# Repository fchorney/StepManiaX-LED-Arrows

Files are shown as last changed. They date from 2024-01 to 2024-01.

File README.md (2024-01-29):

# StepManiaX LED Mirroring Project
The goal of this project is to create 5 3D printed arrows with LEDs in them connected
to your StepManiaX (SMX) stage to mirror the steps that you are stepping.

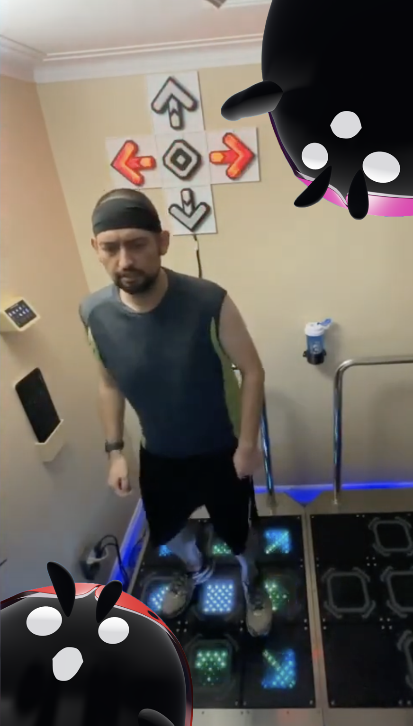
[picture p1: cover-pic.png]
Cover Image


This project requires:
- 3D Printing
- Soldering
- Wire Crimping
- Super Gluing
- Hot Gluing
- Various other small but not insignificant tasks.

Throughout this guide I will be linking all the products I used to create the finished product
but you are by no means required to use exactly the same items I did. This project can be
completed in a number of ways and this is just one.

I will apologize in advance as I have not taken a lot of pictures of this process, but I will
do my best to relay everything I can in Text.

You can see a video of the finished product (The LED Arrows Behind Me) Here:
Finished Product Example (https://www.youtube.com/watch?v=8-Bkg70dLgw)

# Steps

1. [3D print models and combine](./3D%20Prints/README.md)
2. [Oder and populate the PCB](./Circuit/README.md)
3. [Wire necessary cables](./Wiring/README.md)
4. [Putting it all together](./Finishing/README.md)

# Problems? Comments? 
If you had **ANY** problems with this guide, have improvement ideas on the project, or if you think certain sections 
could be expanded or refined, please don't hesitate to let me know.
I encourage you to open up an [Issue](https://github.com/fchorney/StepManiaX-LED-Arrows/issues),
or even a [Pull Request](https://github.com/fchorney/StepManiaX-LED-Arrows/pulls) if you know what you want changed.

I will be sure to check them out, and continue to make this guide better. 

# Future Updates
I already have a big list of upgrades that I want to make to this project for version 2. I can't promise it will happen
any time soon, but hopefully sometime this year. 

Here is a sneak peek of the ideas I want to work on for version 2:
- Snap Connectors for all 3D parts.
  - Trying to avoid as much glue as possible
- Cable channel on backplate could be deeper and wider
  - I personally had some issues fitting 10 x 18AWG stranded wires in the channels
- Backplate connectors need to be better
  - The small connectors really don't do much aside from align the plates. Need a better solution to connect them together
- Design for those JST-SH connectors to snap into the arrow base itself
  - The SH-series connectors are made to fit into holes, maybe leverage this for a better fit and less glue
- Use 20AWG instead of 18AWG in the future probably
  - 18 seems a little big, probably don't need it to be so thick
- Support all 9 panels
- RGB Addressable LEDs
  - Everything can run off of 5v this way, and we have way more options for customizations
- Pico-W Brains
  - This may cause **some** latency since it won't be a purely analog circuit anymore, but this would give crazy customization
  - Different modes, change colors for every step, pulse on freeze, rainbow, etc
- Stream Integration
  - If we use a Pico-W, since it had wifi there is a possibility you could write some code to connect it to twitch chat
and let chat spend points/bits/etc to control the arrows
- Maybe just use screw terminals for all circuit board inputs to be consistent
  - Having to use a handful of different connector types is kind of annoying
- Small PCB LEDs for inputs
  - Might be nice to show what the inputs are with small leds on the pcb
- Can we intercept the SMX data going to the panels to display the judgement color?
  - Theoretically when you hit a panel, it tells the game you hit it and the game judges you and sends back the judgement.
  - We can maybe man in the middle this to figure it out, and actually light our arrows the color the game tells us to.

# Donate
If you appreciate my work and would like to buy me a coffee, I would very much appreciate it. Donations are always welcome,
but never necessary.



# Special Thanks
Big thanks to the [Step Revolution](https://www.steprevolution.com/) crew for making a super fun game, being cool with me
making this kind of stuff, and even helping me out with some aspects of it.

Thanks to [Daaanty](https://www.twitch.tv/daaanty) for giving me some great ideas for the arrow models as well as helping
me track down some of the harder to find connectors. 

Thanks to Cube for making this helpful [SMX Pad to Andamiro Cabinet](https://docs.google.com/document/d/1XnCEbnF3oVle8vsj_GakjsSuEs43jKPMqEG-YfRb-IE/edit#heading=h.98pnc1v5ryli)
guide which helped me confirm some wiring.

Make sure to check out the [Official StepManiaX Discord](https://discord.gg/stepmaniax-430779485026254848) where you
can find a lot of us chatting about SMX and talking about fun projects like this!

# ⚠️ WARNING ⚠️
Making this project and messing with your StepManiaX stages are entirely at your own discretion. 
StepRevolution and I provide absolutely **NO** warranty if something happens to go wrong.

# License
All materials in this project are licensed as [CC BY-NC-SA 4.0](https://creativecommons.org/licenses/by-nc-sa/4.0/) unless otherwise specified.

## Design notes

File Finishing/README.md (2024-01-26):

# Finishing the project

At this point we can assume you have the following items from the previous sections:
- 4 x 3D Printed Arrow Bases + Connected (glued) Insert/Tops
- 1 x 3D Printed Center Base + Connected (glued) Inserts/Tops
- 5 x 3D Printed Back Plates
- 4 x 3D Printer Back Plate Connectors
- 1 x SMX Wire Harness/Splitter (already installed in SMX pad)
- 1 x SMX Molex -> JST XH-Series cable (already installed in SMX pad)
- 1 x Circuit Board (populated and soldered together)

Tools and products you will need for finishing:
- Hot Glue Gun w/ Hot Glue Sticks
- Super Glue
- [12v 7A DC Power Supply](https://www.aliexpress.us/item/1005006333977811.html) 
- [18/20/22 AWG Stranded Hookup Wire (Black, Red)](https://www.aliexpress.us/item/1005002288468147.html)
- [HSC8 6-4 Ferrule Crimper](https://www.amazon.ca/gp/product/B08CXT9Y8L/ref=ppx_yo_dt_b_search_asin_title)
- [Ferrule Terminal Kit](https://www.amazon.ca/Lytool-Insulated-Connectors-Terminals-Single-Line/dp/B0BY2CS16J/ref=sr_1_8)
- [Heat Shrink Tubing](https://www.amazon.ca/Wirefy-180-Heat-Shrink-Tubing/dp/B084GDLSCK/ref=sr_1_5)
- [1/2 Inch Braided Cable Sleeves](https://www.amazon.ca/Pack-33ft-Protector-Expandable-Sleeving/dp/B07ZT9PL72/ref=sr_1_12)
- [JST-SM Male/Female 2P Connectors](https://www.aliexpress.us/item/1005005780885587.html)
- Soldering Station
  - SN63/PB37 Solder
  - Solder Flux

Notes:
- For the 12v power supply, you won't need 7A for just one pad. It's up to you to figure out how many amps you'll need
based on how many LEDs you are powering. 
- For the hookup wire, I opted to use a thicker AWG for going from the circuit board to the LEDs as the distance
travelled is fairly long and I figured a thicker cable would be better in that case. From what I've read, 22 AWG
should realistically be more than enough to carry about 1A of power to each arrow.

## Power Supply
Assuming you bought a similar power supply to the one linked in the materials above, you will need to cut off the DC 
end of the cable and attach some Ferrule ends to the ground and live wires since we're using screw terminals rather
than a barrel jack. 

Simply snip off the barrel jack at the end, expose enough of the 2 wires (typically black and red), remove some of the
wire jacket and terminate with ferrules of the correct size using a ferrule crimper. These will simply go into the 
12v input screw terminals on our circuit board. 

If you are making 2 (for 2 SMX pads) you can terminate some 18AWG (or thicker) wire with ferrules on both ends to daisy
chain the 2 circuit board 12v supplies together. 

## 3D Prints
### Back Plates
At this point we can finish up our 3D prints and wiring for the LEDs. 

Firstly you'll want to super glue all the back plates together. I suggest lining them all up in the plus shape (
4 cardinal arrows and one center panel), use some super glue on the touching edges, add some super glue to the back
plate connector slot and put a back plate connector in each relevant slot (the 4 in the center panel). Leave this alone
to harden over time.

### Arrows
Once the back plates have been securely glued together, you can glue the arrow bases (not the insert/tops) to the 5
back plates. Simply add some super glue to the indent on the bottom of each center/arrow base, line it up with the back
plate so the nub in the middle of the back plate goes in to the base indent, line up the wire holes on the base with
the ones on the back plate, and leave it to harden. This might take a while to harden as the super glue won't really be
exposed to a lot of air there. 

## Wiring
So now we have the backplates and arrow bases securely glued to each other. At this point you're going to want to 
determine how much wiring you will need for each arrow to reach the circuit board for your specific setup. As you can
see in the picture in the base of the repo, my arrows are fairly high up my wall and the wire goes all the way down to
the ground. I determined how much stranded wire I would need for each arrow and cut the pieces. 

For each arrow, you will want to solder your stranded hookup wire (I suggest 18 or 20 AWG) to the opposite type of 
JST-SM connector that you used in the arrow LED section. If you used male for the LEDs, use female for these wires, or
vice versa. What I did was expose wire from the JST-SM connectors, as well as my stranded wire, connected them together,
by twisting, soldered them together and applied some heat shrink to protect the connection. Do this for all 5 pairs of
wire.

At this point you want to route your wire (the non connector side) through the cable holes of the arrow bases/back plates
so that you end up with the connector inside the arrow. Connect the 2 JST-SM connectors, and use some hot glue to provide
strain relief at the holes, and keep all wires down and in place. 

Now that we have wires coming out of the back of all 5 arrows, you essentially want to route them all through the cable
channels on the back of the backplates so they all come out of the bottom arrow. Use hot glue liberally here to keep
them in place and provide strain relief.

This step is optional, but I used 1/2 inch braided cable sleeves to contain all 10 of my wires coming out of the bottom
arrow until it hits my circuit board. Use the cable sleeves, as well as some heat shrink tubing to make it look nice.

Now you can clip the ends of the wire group to be flush if you'd like, and use the ferrule crimper to crimp ferrules
onto the 10 LED wires. 

### Glue Arrow Tops

You can now superglue the arrow inserts/tops onto the arrow bases.

❗Warning: Remember, this is essentially permanent at this point, so make sure all your wiring is correct and working.

## Connecting
Attach these to the circuit board screw terminals that match the arrows. 

⚠️ Remember: If the arrows are behind you, the "right" input should hook up to the "left" arrow if you are looking
straight at them. Thankfully this is easy to reverse if you put it in the wrong way by switching the wires to the other
screw terminal.

Attach the JST-XH 6 pin connector coming out of your SMX stage onto the circuit board. 

Connect the power inputs (and outputs if you have them) to the circuit board.

## Mount Arrows
Stick your arrows and backplates to your wall somehow! That's up to you to figure out.

What I did was use about 8 x [3M Command Strips](https://www.command.com/3M/en_CA/p/d/v000584005/) at various points
on the back of the backplates to stick to my wall. Fairly clean and easy to remove if necessary. 

# Enjoy

Congratulations! At this point you should be finished! Turn on StepManiaX, plug in your 12v power supply and dance your
heart out! 

⚠️ If you had any issues with this guide, questions, or comments I encourage you to please open up an issue in this
repository.

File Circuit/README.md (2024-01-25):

# Circuit and PCB
I have included the necessary files to have the PCB manufactured or perf-boarded for your use. 

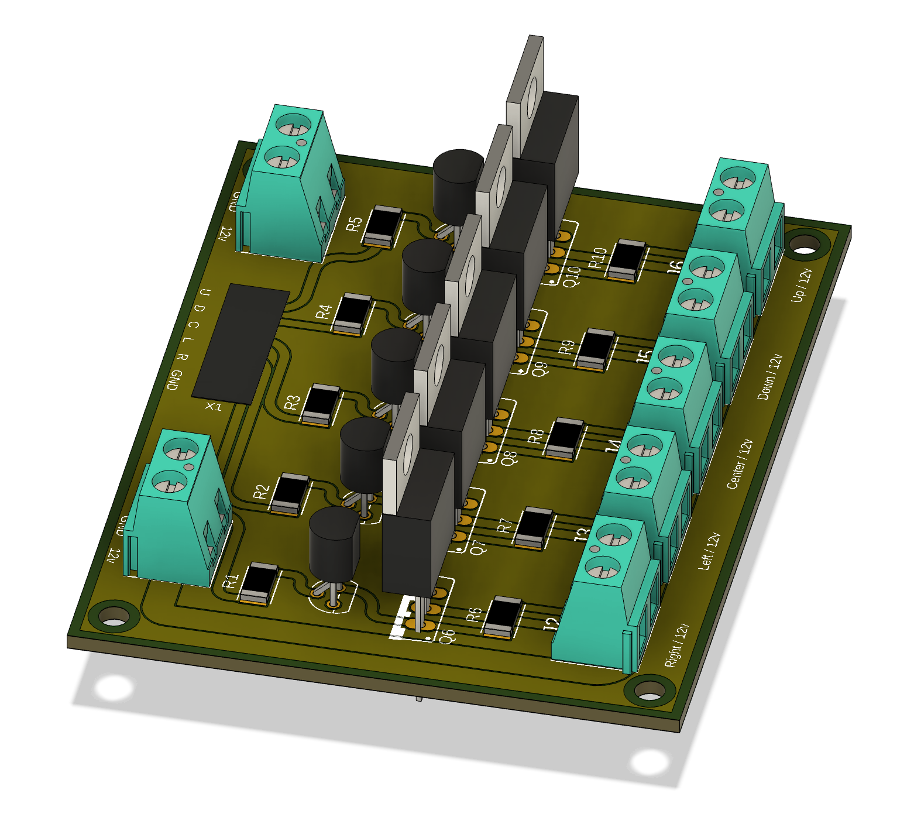
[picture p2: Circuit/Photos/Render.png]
3D Render


## Schematic
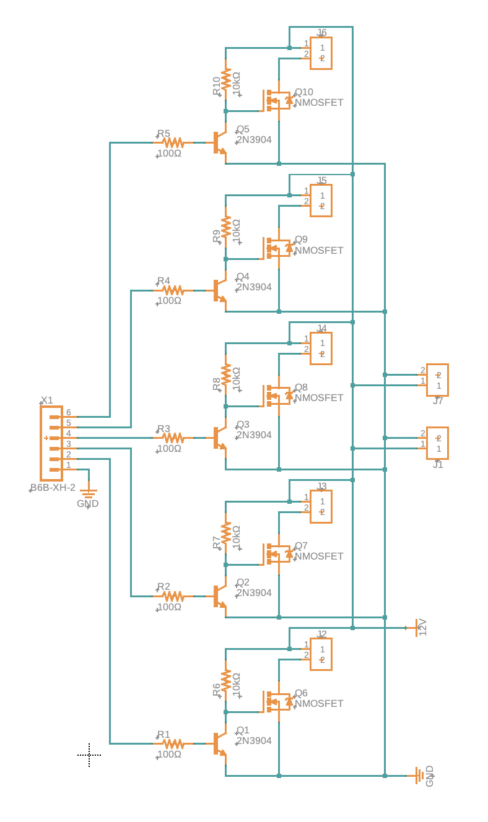
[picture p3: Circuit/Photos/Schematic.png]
Schematic


The schematic is fairly simple. We take 5 arrow data lines, plus ground, into the 6 pin JST connector, and
a 12v power supply into one of the power screw terminals. The 12v are to power the LEDs as I was using 12v single 
colour LEDs for my implementation. 

The data lines coming out of the StepManiaX panel boards sit high (5v) and when the press threshold is reached
they are pulled down to ground (0v). Since my board needs to pull the LED ground pins to ground when the SMX
panel is also pulled to ground, I had to create a logic inverter since I'm using MOSFETs to drive the 12v LEDs from
the 5v SMX logic.  

The 5v logic is passed through a 100Ω resistor into the base of a BJT
([2n3904](https://www.onsemi.com/pdf/datasheet/2n3903-d.pdf)). The collector for the BJT goes into the MOSFET
([BUZ11](https://www.onsemi.com/pdf/datasheet/buz11-d.pdf)) gate and will pull it to ground when the BJT receives a
high 5v signal since the BJT Emitter is connected to ground. When the BJT is inactive (the SMX panel signal is pulled to
ground when the panel is pressed), the MOSFET gate is connected to a 10kΩ pullup to the 12v line thus activating the
MOSFET to connect the Drain (connected to the LED Arrow) to ground, completing the circuit. 

The second 12v screw terminal on the input side, is to daisy chain 12v to a second board for a second SMX pad if you 
are planning to make two. You should note that you will want to make sure your 12v power supply can handle both boards.
I guestimated the density of LEDs on my arrows would use about 1A for each arrow, and I think in general you'd be
hitting 6 arrows max and probably hardpressed to even do that, so 7A should be more than enough for 2 pads. 

## Bill of Materials (BoM)

Realistically, most of the items I used in my circuit can be interchanged with any other part that fits the criteria. 
This BoM will list exactly what I used and where you can find it, but if you have similar parts already, you can use
those instead. Specifically the MOSFETS, as I only used BUZ11 since I had a bunch lying around.

- R1, R2, R3, R4, R5: [100Ω 2010 SMD Resistor](https://www.digikey.ca/en/products/detail/yageo/RC2010FK-07100RL/5920949)
- R6, R7, R8, R9, R10: [10kΩ 2010 SMD Resistor](https://www.digikey.ca/en/products/detail/stackpole-electronics-inc/RMCF2010FT10K0/1758376)
- Q1, Q2, Q3, Q4, Q5: [NPN BJT Transistor 2N3904 TO92](https://www.digikey.ca/en/products/detail/onsemi/2N3904BU/1413)
- Q6, Q7, Q8, Q9, Q10: [BUZ11 N-CH MOSFET](https://www.digikey.ca/en/products/detail/onsemi/BUZ11-NR4941/1954150)
- J1, J2, J3, J4, J5, J6, J7: [2P Terminal Block Side ENT 5.08mm PCB](https://www.digikey.ca/en/products/detail/phoenix-contact/5442206/4390264) 
- X1: [B6B-XH-A](https://www.digikey.ca/en/products/detail/jst-sales-america-inc/B6B-XH-A/1000381)

### Notes
- I personally accidentally bought 1206 sized resistors for my board, but the correct size is 2010.
  - If you are doing this on a perf-board or something you can use through-hole resistors if you want.
- The BUZ11 MOSFETs look unavailable at the digikey link I added up there, so you'll have to find some alternative. 
  - I'm certainly no expert, but I think you could use: [FQP30N06L](https://cdn.sparkfun.com/datasheets/Components/General/FQP30N06L.pdf),
[IRFZ44N](https://www.infineon.com/dgdl/Infineon-IRFZ44N-DataSheet-v01_01-EN.pdf?fileId=5546d462533600a40153563b3a9f220d),
[IRF640](https://www.vishay.com/docs/91036/sihf640.pdf), or some other N-Channel Power MOSFET.
- For the `B6B-XH-A` JST connector, remember that you will need [XHP-6](https://www.digikey.ca/en/products/detail/jst-sales-america-inc/XHP-6/1651016)
and [SXH-001T-P0.6N](https://www.digikey.ca/en/products/detail/jst-sales-america-inc/SXH-001T-P0-6N/7041446) to connect
wires to this terminal. This will be covered more in the `wiring` section of this guide. 

## Manufacturing the PCB

I personally have been using [JLCPCB](https://jlcpcb.com/) to manufacture my hobby boards as they are very cheap,
decent quality, and fairly quick to ship. I have included the
[SMX LEDs JLCPCB Gerber](Files%2FSMX%20LEDs%20JLCPCB%20Gerber.zip) archive in this repo, so you can just plug that into
JLCPCB and have it manufactured. I typically just keep all defaults, else you start incurring extra charges. I may have
a few boards left, so if you reach out I may be able to send you one or two for a good price.

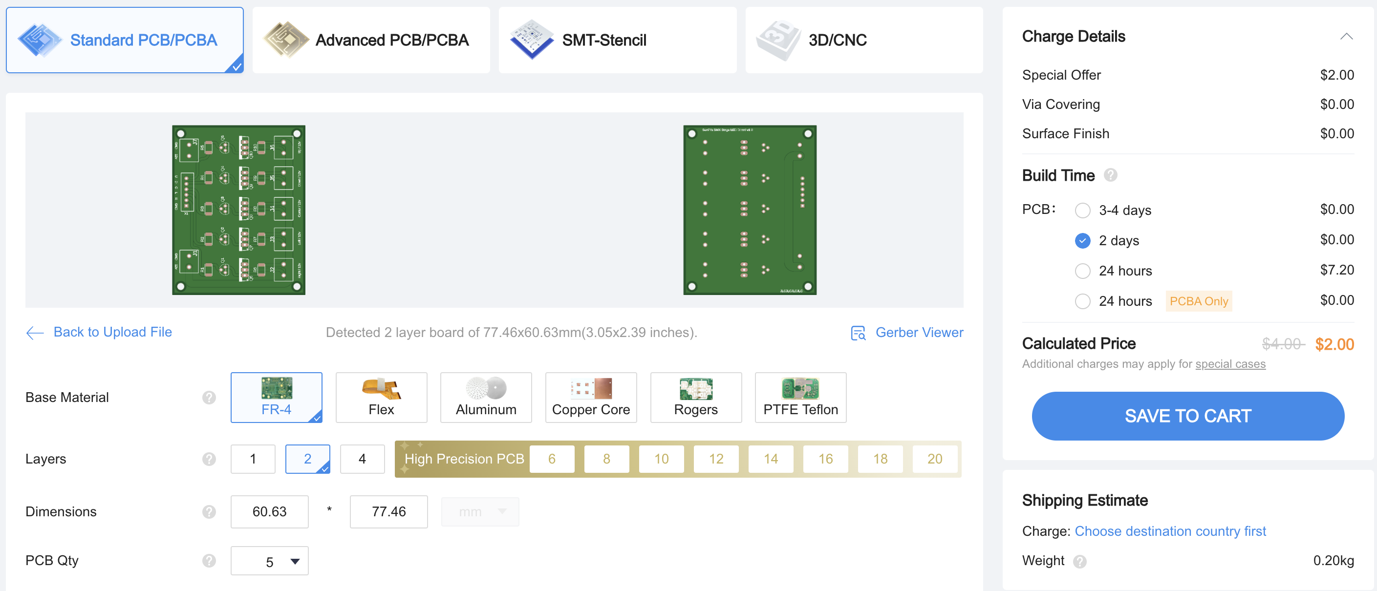
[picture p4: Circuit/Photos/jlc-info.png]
JLCPCB Order Info


The only JLCPCB option you may want to set is the `RemoveOrderNumber` option. Set it to `Speceify a location` as the
board follows the instructions to place their order number in a specific location instead of it randomly appearing 
somewhere on the board. 

JLCPCB Order Number Option

## Soldering

This guide assumes that if you are getting this PCB manufactured that you have the knowledge to solder it all together.
Typically you want to solder parts from shortest to tallest, so start with the resistors, then the BCJ transistors and
6 pin JST connector, the screw terminals, and finally the MOSFETs.

## Enclosure
I had plans to model and 3D print an enclosure for the board as well, but I haven't gotten around to it. I will
update this guide and add it in once I do.

# License
The circuit and hardware files found in this folder are licensed under
[CERN OHL v2 Permissive](https://choosealicense.com/licenses/cern-ohl-p-2.0/).

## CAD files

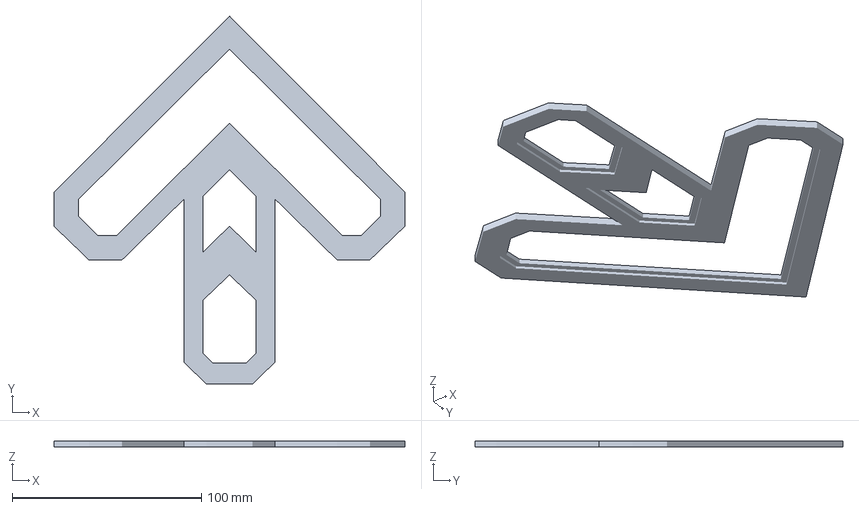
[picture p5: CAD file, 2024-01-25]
3D Prints/Models/3MF for Bambu Labs X1-Carbon/X1C - Arrow Insert for 3 Piece.3mf
185.4 x 194.4 x 3.00 mm

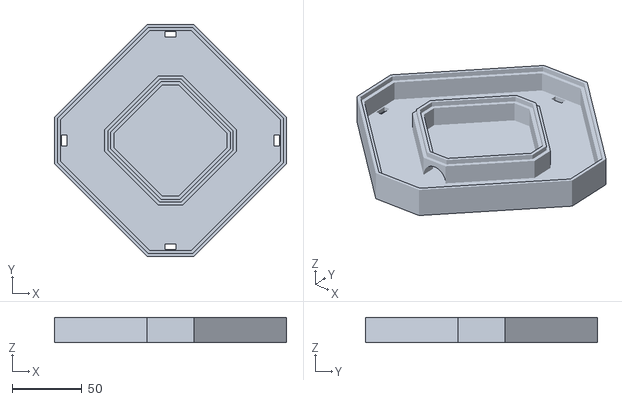
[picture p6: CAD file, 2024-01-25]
3D Prints/Models/STL/Center Base.stl
166.2 x 166.2 x 18.0

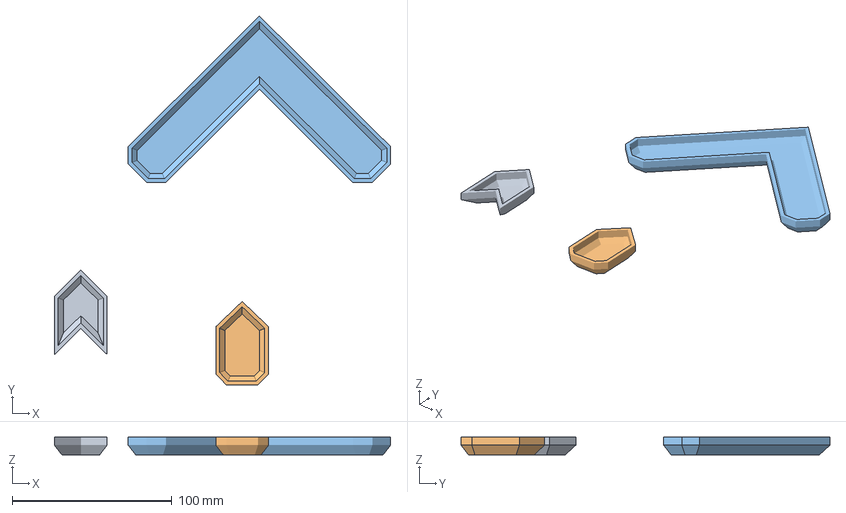
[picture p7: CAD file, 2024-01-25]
3D Prints/Models/3MF for Bambu Labs X1-Carbon/X1C - Arrow Tops for 3 Piece.3mf
210.5 x 231.0 x 11.0 mm
Arrow Top Body for 3 Piece.stl
Arrow Top Tail for 3 Piece.stl
Arrow Top Head for 3 Piece.stl

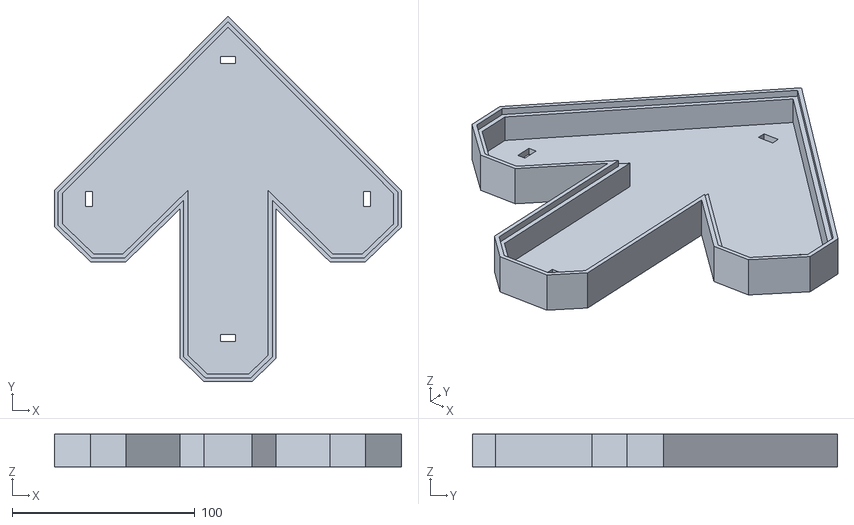
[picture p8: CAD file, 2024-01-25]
3D Prints/Models/STL/Arrow Base.stl
190.0 x 200.0 x 18.0

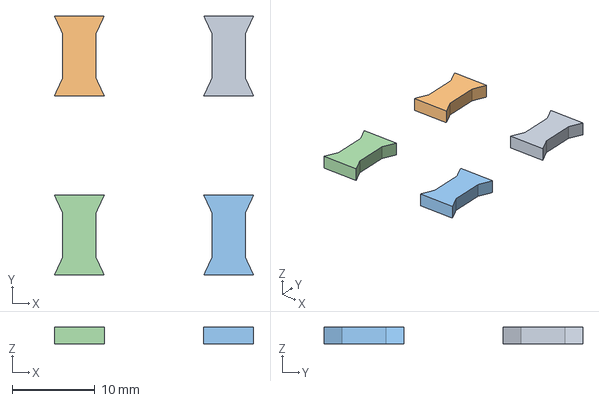
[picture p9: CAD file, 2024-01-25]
3D Prints/Models/3MF for Bambu Labs X1-Carbon/X1C - Back Plate Connector.3mf
24.0 x 31.3 x 2.00 mm
Back Plate Connector.stl x 4

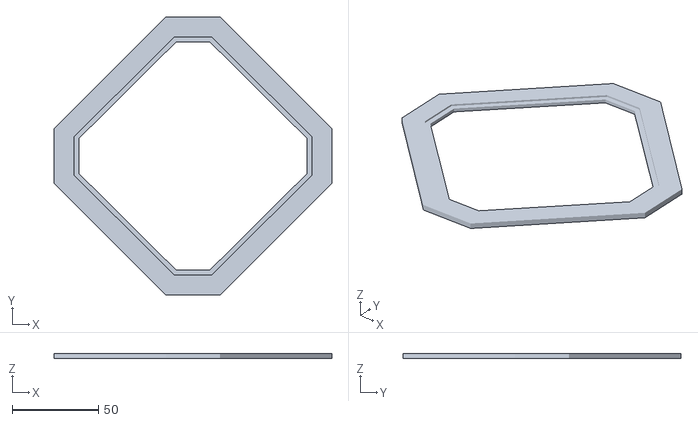
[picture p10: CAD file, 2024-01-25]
3D Prints/Models/STL/Center Insert Outer.stl
161.6 x 161.6 x 3.00

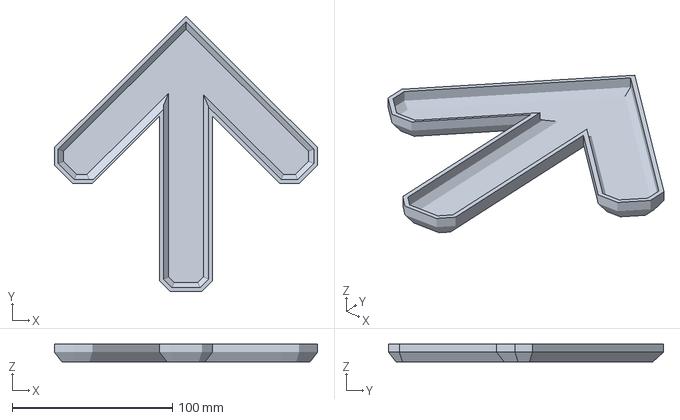
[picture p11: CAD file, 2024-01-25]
3D Prints/Models/3MF for Bambu Labs X1-Carbon/X1C - Arrow Top for 1 Piece.3mf
164.3 x 171.7 x 11.0 mm

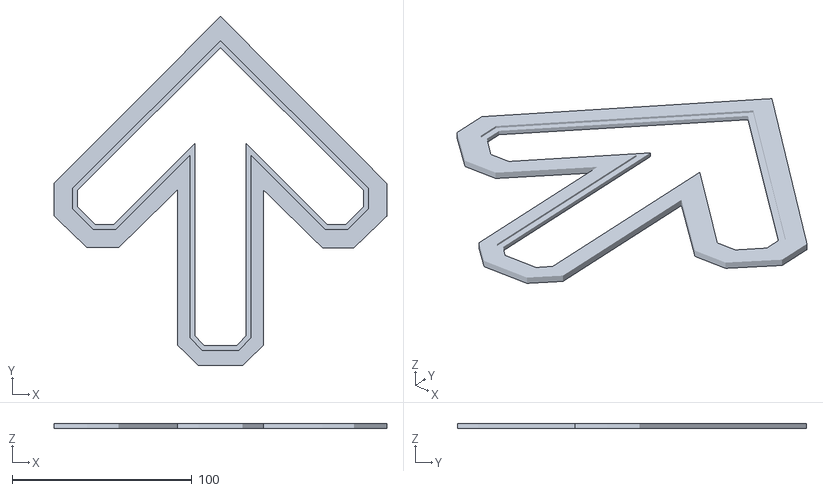
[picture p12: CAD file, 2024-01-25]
3D Prints/Models/STL/Arrow Insert for 1 Piece.stl
185.4 x 194.4 x 3.00

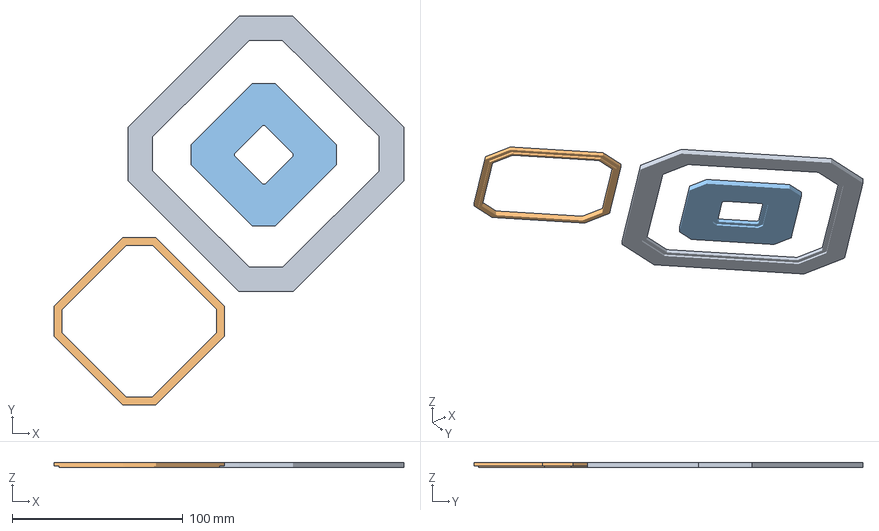
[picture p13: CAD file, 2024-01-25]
3D Prints/Models/3MF for Bambu Labs X1-Carbon/X1C - Center Inserts.3mf
204.9 x 228.0 x 3.00 mm
Center Insert Outer.stl
Center Insert Middle.stl
Center Insert Inner.stl

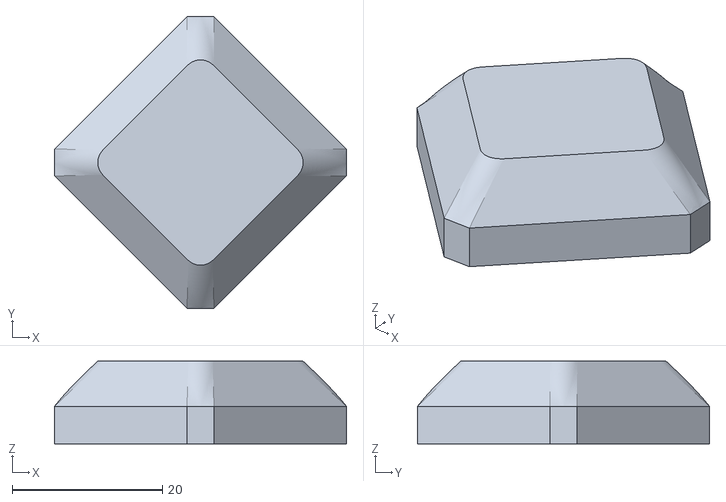
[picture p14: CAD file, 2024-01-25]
3D Prints/Models/STL/Center Top Inner.stl
38.9 x 38.9 x 11.0

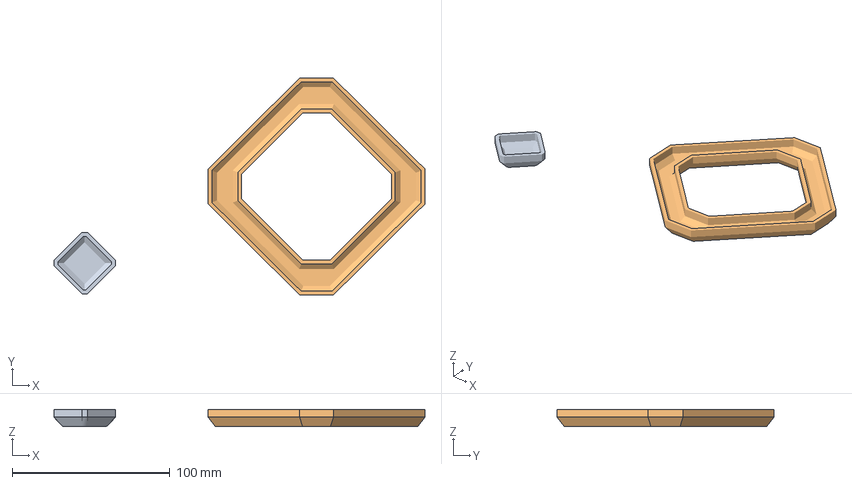
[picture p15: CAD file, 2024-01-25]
3D Prints/Models/3MF for Bambu Labs X1-Carbon/X1C - Center Tops.3mf
235.3 x 137.6 x 11.0 mm
Center Top Inner.stl
Center Top Outer.stl

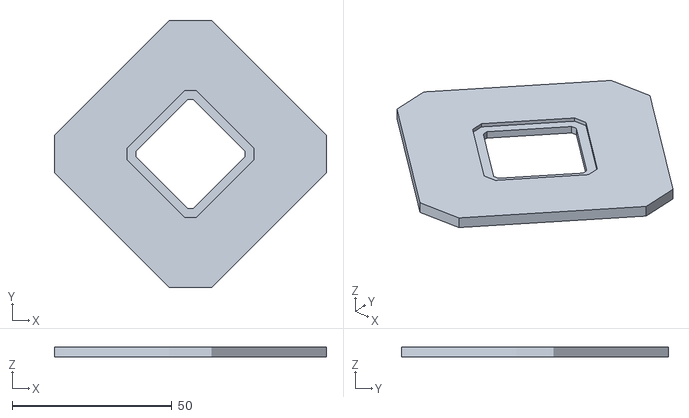
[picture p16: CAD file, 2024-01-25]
3D Prints/Models/STL/Center Insert Inner.stl
85.2 x 83.6 x 3.00

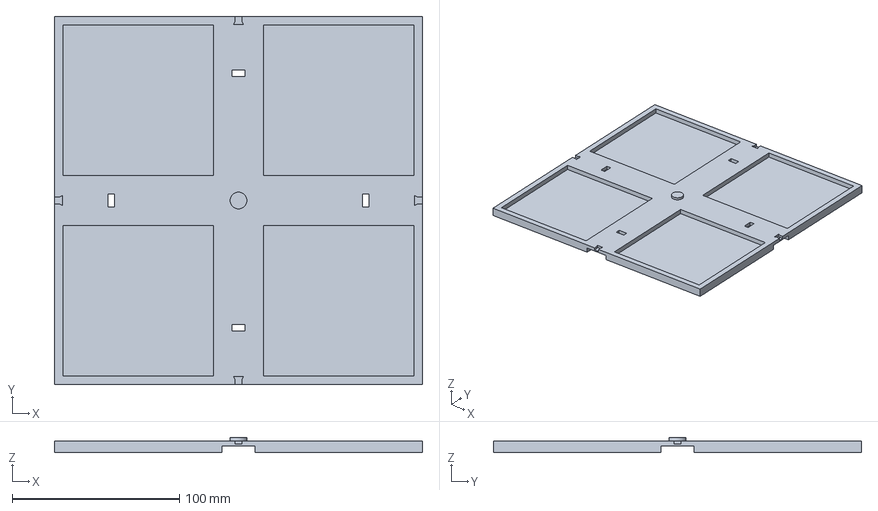
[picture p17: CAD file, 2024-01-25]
3D Prints/Models/3MF for Bambu Labs X1-Carbon/X1C - Back Plate.3mf
220.0 x 220.0 x 9.00 mm

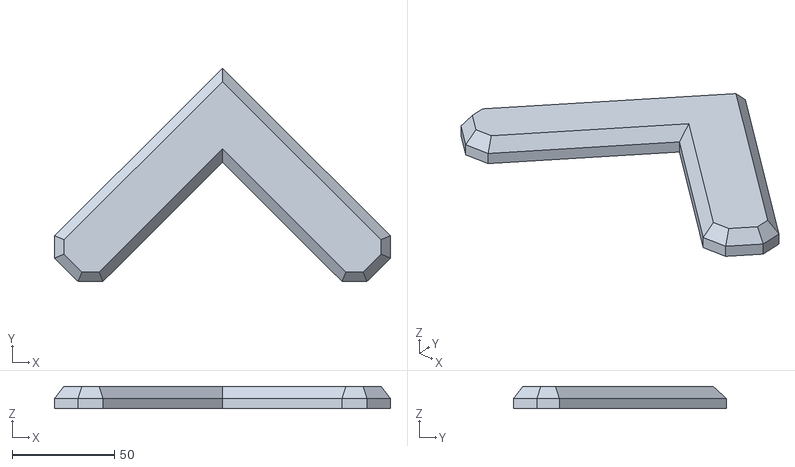
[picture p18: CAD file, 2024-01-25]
3D Prints/Models/STL/Arrow Top Head for 3 Piece.stl
164.3 x 104.2 x 11.0

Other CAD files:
3D Prints/Models/STL/Arrow Insert for 3 Piece.stl
3D Prints/Models/3MF for Bambu Labs X1-Carbon/X1C - Center Base.3mf
3D Prints/Models/3MF for Bambu Labs X1-Carbon/X1C - Arrow Insert for 1 Piece.3mf
3D Prints/Models/STL/Arrow Top Tail for 3 Piece.stl
3D Prints/Models/3MF for Bambu Labs X1-Carbon/X1C - Arrow Base.3mf
3D Prints/Models/SMX Items v2.f3d
3D Prints/Models/STL/Arrow Top Body for 3 Piece.stl
3D Prints/Models/STL/Arrow Top for 1 Piece.stl
3D Prints/Models/STL/Back Plate Connector.stl
3D Prints/Models/STL/Back Plate.stl
3D Prints/Models/STL/Center Insert Middle.stl
3D Prints/Models/STL/Center Top Outer.stl

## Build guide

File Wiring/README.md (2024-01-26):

# Wiring
This section explains how I wired everything together, what wires and connectors I used, where to get them, and what
tools you will need. 

This section assumes you have the arrows all printed, and the circuit board finished. We will cover adding LEDs and
wires to the arrows, making a splitter for the SMX Data lines, and connecting it all together.

# Bill of Materials (BoM)

## Wiring
- [18/20/22 AWG Stranded Hookup Wire (Black, Red)](https://www.aliexpress.us/item/1005002288468147.html)
- [JST-SM Male/Female 2P Connectors](https://www.aliexpress.us/item/1005005780885587.html)
- [22 AWG 6 Core Cable](https://www.aliexpress.us/item/4000570401041.html)
- [22 AWG 9 Core Cable](https://www.aliexpress.us/item/4000570401041.html)
- [12v DC 60LEDs/M LED Strip](https://www.aliexpress.us/item/1005002934660865.html)

# Connectors
- [YLR-09V JST YL-Series Receptacle](https://www.digikey.ca/en/products/detail/jst-sales-america-inc/YLR-09V/9921747)
- [YLP-09V JST YL-Series Plug](https://www.arrow.com/en/products/ylp-09v/jst-manufacturing)
- [SYF-01T-P0.5A 20-26 AWG Crimp Socket](https://www.arrow.com/en/products/syf-01t-p0.5a/jst-manufacturing?q=SYF-01T-P0.5A)
- [SYM-01T-P0.5A 20-26 AWG Crimp Pin](https://canada.newark.com/jst-japan-solderless-terminals/sym-01t-p0-5a/contact-pin-26-20awg-crimp/dp/57AC7552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)
- [WM1781 10 Pin Molex Plug](https://www.digikey.ca/en/products/detail/molex/0430201000/252494)
- [WM1787 10 Pin Molex Receptacle](https://www.digikey.ca/en/products/detail/molex/0430251000/252500)
- [WM1841CT Molex 20-24 AWG Crimp Pin](https://www.digikey.ca/en/products/detail/molex/0430310001/467798)
- [WM1837CT Molex 20-24 AWS Crimp Socket](https://www.digikey.ca/en/products/detail/molex/0430300001/467796)
- [XHP-6 JST XH-Series 6 Pin Receptacle](https://www.digikey.ca/en/products/detail/jst-sales-america-inc/XHP-6/1651016)
- [SXH-001T-P0.6N JST XH-Series Crimp Socket](https://www.digikey.ca/en/products/detail/jst-sales-america-inc/SXH-001T-P0-6N/7041446)

# Tools & Other
- [SN-28B Pin Socket Terminal Crimper](https://www.amazon.ca/Terminal-Crimping-Ratchet-Crimper-Connector/dp/B075NY2YM6/ref=sr_1_12)
- [Insulated Wire Terminal Crimper](https://www.amazon.ca/gp/product/B01IQIALJC/ref=ppx_yo_dt_b_search_asin_title)
- [Fork/Spade Terminal Kit](https://www.amazon.ca/Twidec-Insulated-Connectors-Assortment-N-021-250PCS/dp/B0BB25LSF2/ref=sr_1_4)
- [Heat Shrink Tubing](https://www.amazon.ca/Wirefy-180-Heat-Shrink-Tubing/dp/B084GDLSCK/ref=sr_1_5)
- Small Pliers
- Cable Snips
- Soldering Station
  - SN63/PB37 Solder
  - Solder Flux
- Super Glue

## Notes

- You should be able to buy most of this stuff on Amazon, or AliExpress (which I have linked above), or possibly
other websites as well.
- You will need to determine the length of your wiring needs.
- For the LED strips, I found that the arrows used 12 sections of 3 LEDs each, and the center panel used 13 sections
of 3 LEDs each.
- If you can't source 6 and/or 9 core cable, you can just use loose hookup cable.

### JST YL-Series
I have personally found that the YL-Series connectors/pins/etc have been extremely hard to come by. This connector is
what the SMX pads use internally for the data connections that we want to connect to, which is why I spent too much 
money on shipping just to get the correct parts. One possible alternative would be to use 
[T-Taps](https://www.amazon.ca/Ginsco-Connectors-Terminals-Electrical-Self-Stripping/dp/B09YGH6FNQ/ref=sr_1_4), but this
is generally thought to be a weaker solution, but will work in a pinch.

## Connecting the LEDs to the Arrows
Thankfully I actually have a video for this part. Though a few things in the video are incorrect compared to this guide.
Initially I was using dupont connectors for the LED connections, but have since switched to JST-SM connectors instead.

The video covers super gluing the arrow pieces together, soldering wires to the LEDs, gluing the LEDs into the arrow
bodys, and connecting them all up. You can watch the video here: https://www.youtube.com/watch?v=dij5LlBn8TU

The tl;dr for this would be:
- Super glue the `top` arrow pieces to the `insert` arrow pieces for all arrows and center.
- Prep your LED strips by cutting them to size, applying solder to the contacts, and wiring them up
- Super glue the LED strips into the arrow bodies as shown in the video
- Solder the JST-SM connectors to the LED strips (the video shows Dupont)
  - You can use either the male or female JST-SM connectors here, just be sure to use the opposite for the `finishing`
section.

At this point you are done with the arrows **for now**. 

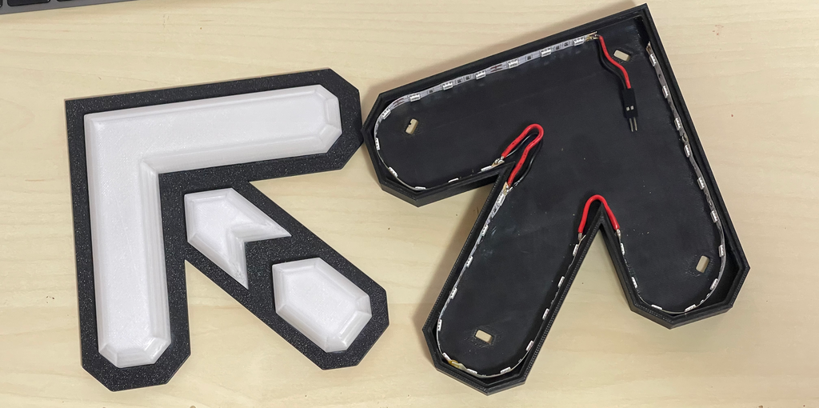
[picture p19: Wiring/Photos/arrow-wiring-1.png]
Arrow Wiring

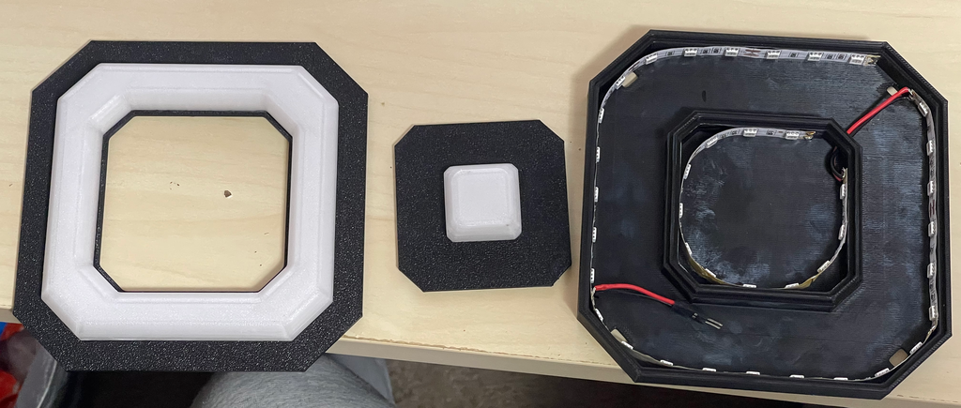
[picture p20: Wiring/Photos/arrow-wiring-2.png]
Center Wiring


## Creating the SMX Pad Harness
This harness is essentially what we will be looking to make. This will intercept the pad signal data and split it out
so that it continues to be connected to the pads controller, as well as our circuit board. I have opted to make a 3 way
split, but in general I would suggest just making it a 2 way as it will be less complicated. 

SMX Harness

To achieve this, you will need the following items:
- 1 x YLR-09V Receptacle
- 1 x YLP-09V Plug
- 9 x SYF-01T-P0.5A Crimp Socket
- 9 x SYM-01T-P0.5A Crimp Pin
- 2 x WM1787 Receptacle (or just 1 if making a dual split)
- 20 x WM1837CT Socket (or just 10 if making a dual split)
- 3 x 15cm Piece of 9 Core Cable (or just 2 if making a dual split)
- 1 x 22AWG Fork Terminal
- 2 x 20cm Piece of 22AWG Stranded Cable (or just 1 if making a dual split)

To start off, we can check the current connections, and make a note of where the cables should go in the connectors.
Inside 1
Inside 2
Inside 3
Inside 4

The connector connected to the panels themselves seems to be a YLR-09V Receptacle, and the connector going to the
stage controller is a YLP-09V Plug. Thus we want to connect our triple splitter to our YLP-09V Plug so that we split the
signal coming out of the panel connectors. 

We can also infer the position of the connectors from these pictures, as well as this one which details which color is
connected to which panel.  
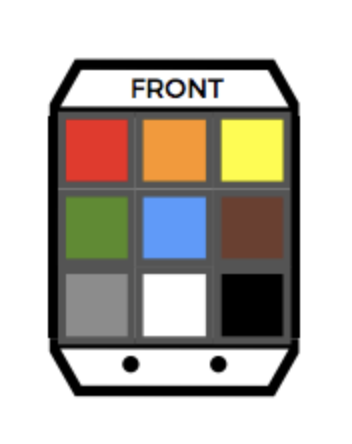
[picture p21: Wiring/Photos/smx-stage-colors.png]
SMX Stage Colors


Now, at this point we have a small issue that we will need to document so we can be sure we are connecting the right
connections together. The 9 core cable I have **almost** exactly matches the colors in the pad, but not quite. You'll
want to write down what colors from the panels match up with whatever wires you are using. For me, all the colors except
grey matched up, and in my case grey from the panel would match up with purple from my cable. 

As I was making a triple splitter as well I opted to actually solder my wires to the crimp connectors, and add heat
shrink as well. This part can be fairly difficult as these connectors arent typically meant to connect multiple wires
to a single connector. Your mileage may vary. 

For each cable that I needed to connect I did the following:
- Remove about 1-1.5 inches of insulation from the end of each cable
- Grab all of the same colors wires that you need and remove a small bit of insulation to expose the wires (about 4mm)
- Twist the 3 wires together and solder them together
- Add some heat shrink to the wire behind the soldered end and heat it to hold the 3 wires together
- Put an extra bit of heat shrink on the wire before crimping for use later
- Snip off any extra wire and connect it to the SYM-01T-P0.5A using a set of pliers to hold it all in place
- Use the SN-28B crimper to properly crimp the connector
- Apply a bit of solder to the crimp pin and wires where they connect. This is optional as these conectors are meant to
be solder-less.
- Move the heat shrink piece we previously left on the wires up to the crimped and soldered connector and heat to protect
the crimp.

After doing this for the 9 wires I added a bit more heatshink over each 9 core end for a bit of straing relief and to
compress them a bit.

If you want, you can electrically test your connections with a multimeter to make sure the pins are properly connected
to each end. 

From here we have 3 more connectors to connect, but these should be much easier as we are doing single cables.

First you can connect one of the 9 core conductors to the YLP-09V Receptacle using pliars and/or a crimping tool.
Take note that the left to right order of the colors will be reversed.
For example here is the mapping for my cable colors.

SMX 9 Cable to 9 Conductor Wire (Almost 1:1, SMX Grey is Wire Purple)

1 (Up-Left) - SMX Red    -> Wire Red  
2 (Up) - SMX Orange -> Wire Orange  
3 (Up-Right) - SMX Yellow -> Wire Yellow  
4 (Left) - SMX Green  -> Wire Green  
5 (Center) - SMX Blue   -> Wire Blue  
6 (Right) - SMX Brown  -> Wire Brown  
7 (Down-Left) - SMX Grey   -> Wire Purple  
8 (Down) - SMX White  -> Wire White  
9 (Down-Right) - SMX Black  -> Wire Black  

SMX Wire Colors to JST Connector (Hook on bottom, Male, looking at wire input side. This may look upside down as the
connector hook is on the bottom of the connector)

7 : 8 : 9  
4 : 5 : 6  
1 : 2 : 3  

9 Conductor Wire to JCT Connector (Hook on bottom, Female, looking at wire input side)

9 : 8 : 7  
6 : 5 : 4  
3 : 2 : 1  

This can be a bit confusing, but you just need to make sure that the same color is going to the same color regardless
of the YL-Series connector you are making.

After this you can connect your 2 (or 1) 10-pin molex connectors. I opted for a 10-pin molex as we need to grab the
ground pin as well. As you can see in the finished image, I opted to combine the 2 x 22AWG ground cables together into
a fork terminal (you'll see why I used this later) that connect to the 2 10-pin molex connectors. I just used some heat
shrink to hold these together with the other cables.

Similarly to the YLP-09V, you will want to make a mapping for the 9 core cable to the molex pins. Here is mine:

9 Conductor Wire to Molex 10 Pin (Hook on top, Female, looking at wire input side)

5 : 4 : 3 : 2 : 1  
G : 9 : 8 : 7 : 6

(G is Ground)

Molex 1
Molex 2

As you can see in the photo's, I didn't do both, I just wrapped one of the branches off with some electrical tape.

You should have a similarly finished cable harness:

SMX Harness Finished

Once again, you might want to test the electrical connections with a multimeter to make sure it's all correct.

Now it's time to install. The area you want to get into is the middle section of the front of the stage. You will need to remove the 6 screws with
the smaller allen wrench that you received with your stage(s).

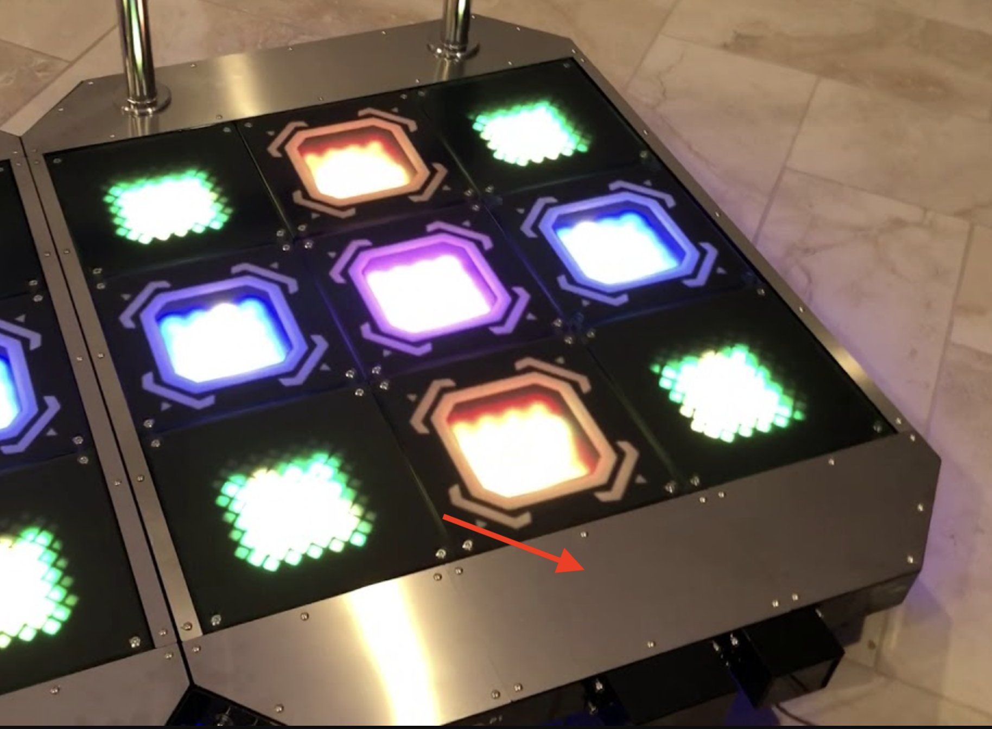
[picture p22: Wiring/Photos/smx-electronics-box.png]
SMX Electronics Box


You can install this into your SMX pad by unplugging the original YL-Series connectors for the stage wires (shown in 
the picture with red arrows. I have already split them here), and placing
your harness inbetween them. One last thing you'll want to do, is connect the harness ground we made to the 5v 
ground terminal from the 12v -> 5v converter (shown in blue).

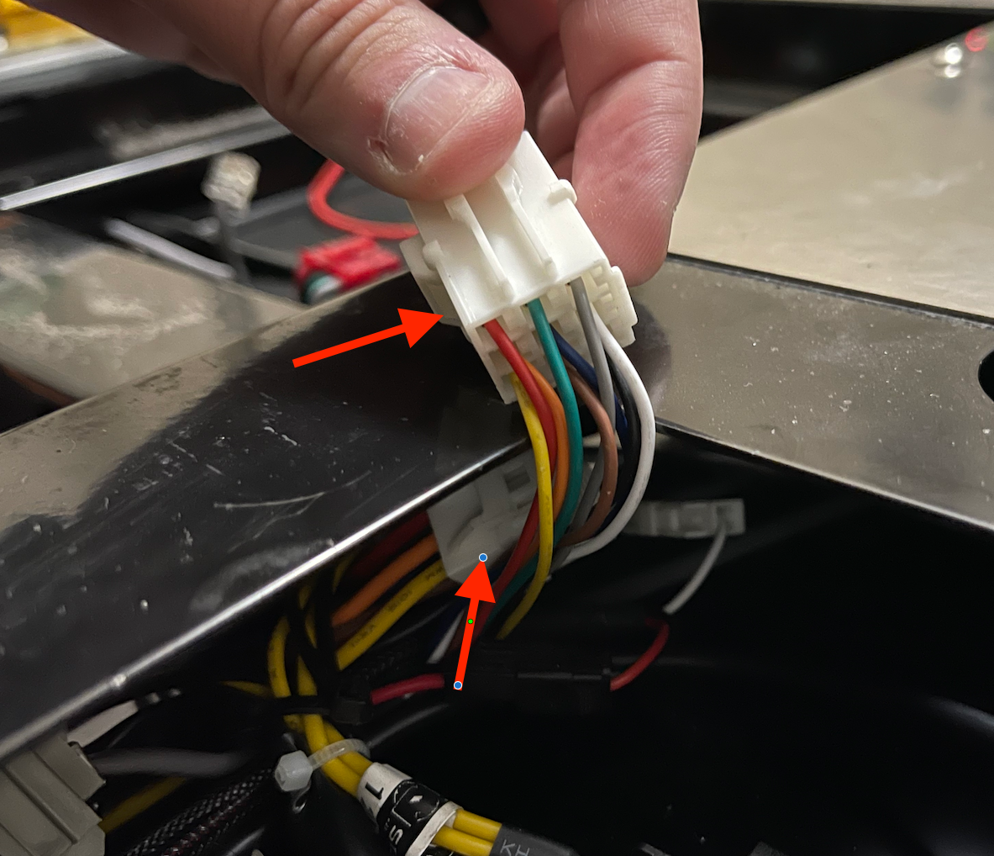
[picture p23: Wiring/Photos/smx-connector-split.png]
SMX Split Connection

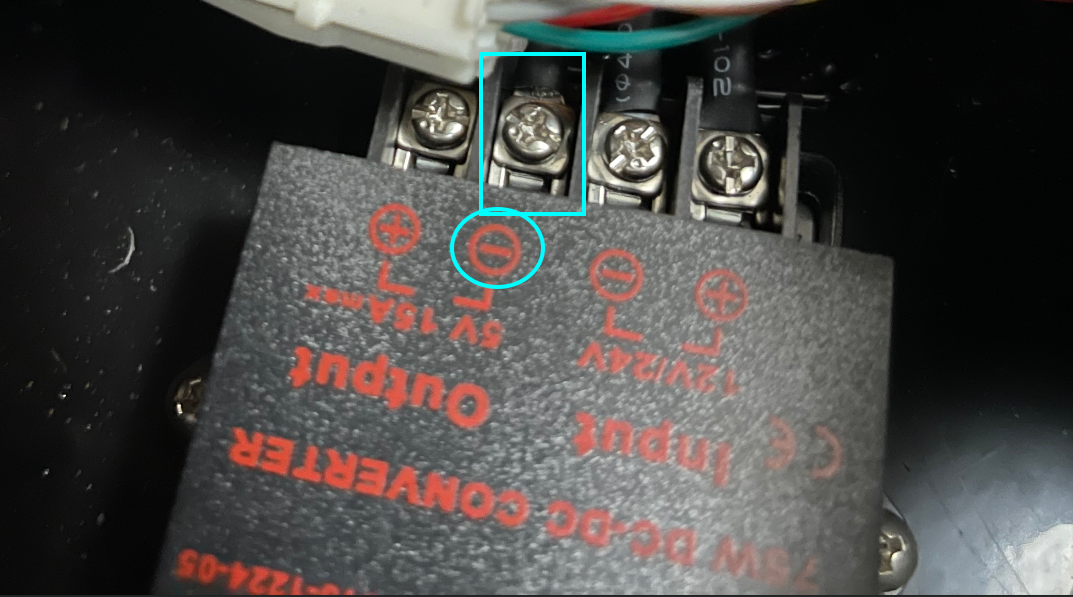
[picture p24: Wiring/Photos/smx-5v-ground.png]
SMX Ground Connection


Turn your game back on and make sure your pad still works correctly with the game. If done properly, you should notice
no changes. 

## Creating the 6 core Pad to PCB Cable

The next cable we are going to need is the Molex 10-pin to JST XH-Series 6 pin to connect to the circuit board. 
Apologies as I don't have any pictures of this. 

Once again, the 6 core wire has different wire colors that don't necessarily match up with the SMX panel wire colors.
Here is my mapping for what I had:

6-Core Black = Ground  
6-Core Orange = 2 (Up) - Molex Orange  
6-Core Green  = 4 (Left) - Molex Green  
6-Core Yellow = 5 (Center) - Molex Blue  
6-Core Red    = 6 (Right) - Molex Brown  
6-Core White  = 8 (Down) - Molex White  

Molex 10 Pin to 6 Conductor Wire (Hook on top, Male, looking at wire input side)

X : 2 : X : 4 : 5  
6 : X : 8 : X : G

Once again just a reminder to double check your connections that they are mapping to the correct signals that you care
about. This can be tricky when you are dealing with different coloured wires, so make your own mapping and double
check everything. 

As some of the above instructions, you just want to crimp the molex wires, and crimp the JST XH-series pins on the other
side using a crimper or pliers. I don't think the tools I have are meant to crimp the very tiny XH-series sockets, so I 
tend to just do it with some pliers manually. 

## Cable Routing Through Pad

At this point you'll want to route this new cable through your SMX pad. You will need to remove the top panels as well
as the panel mounts under there. As you can see in this image, you will need to unscrew the 8 screws (shown in red),
and un-connect all cables shown in blue (the signal cable needs to be unscrewed from the screw terminal to come out). 
For the panels that have sensors, you might need to remove the rubber corners to get to the 8 screws. You should 
**NOT** need to unplug the FSR sensors to remove the panel mounts. 

SMX Circuit Board

Remove the 3 left panels and panel mounts, connect the molex side to the splitter/harness you made and installed
earlier, and route it through the pads as shown here:

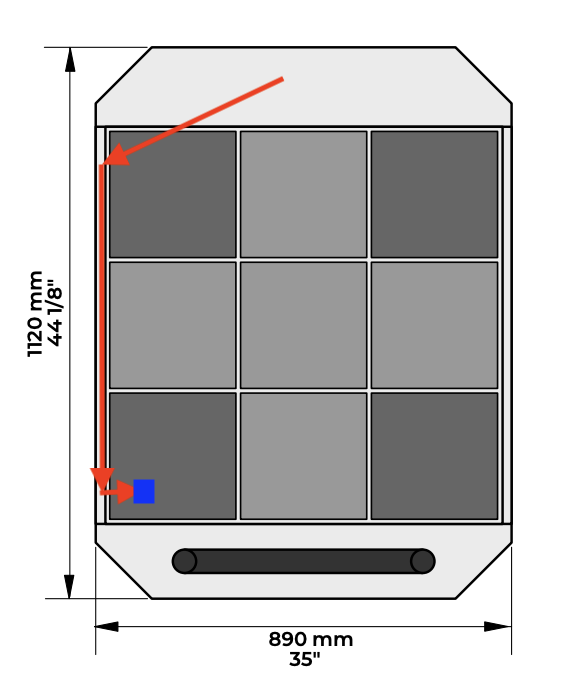
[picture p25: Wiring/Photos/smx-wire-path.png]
SMX Wire Path


As shown in the above image, there are various walls, holes, etc in the stage so you'll need to route the cable around
or through them. If you want you can probably route this on the right or left side as I believe it is symmetric.
From the front box, you'll go left and you'll find some gaps near the bottom of the walls, so slide the cable under 
the walls to get into the top left panel box. 

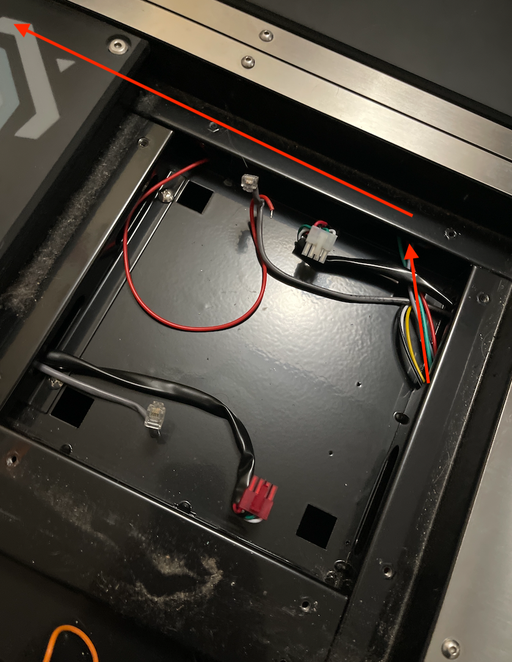
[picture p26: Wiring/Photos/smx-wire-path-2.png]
SMX Wire Path 2


You will want to try and feed your cable through the hole shown above and into the hole the arrow is pointing to. The
side of the pads have a cable channel that you want to run your cable through all the way to the bottom left panel.
Once you reach the bottom left panel, pull your cable out of the channel and route it out of one of the 4 holes
on the bottom of the pad. Make sure you pull as much slack as you need, and you should be able to put all the panels
back on in reverse order of how you took them off in the first place. 

Congratulations, your wiring should be done..... for now, there's actually more in the `Finishing` section.

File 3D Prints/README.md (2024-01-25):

# 3D Prints
This step requires you to print all the necessary models and put them together.

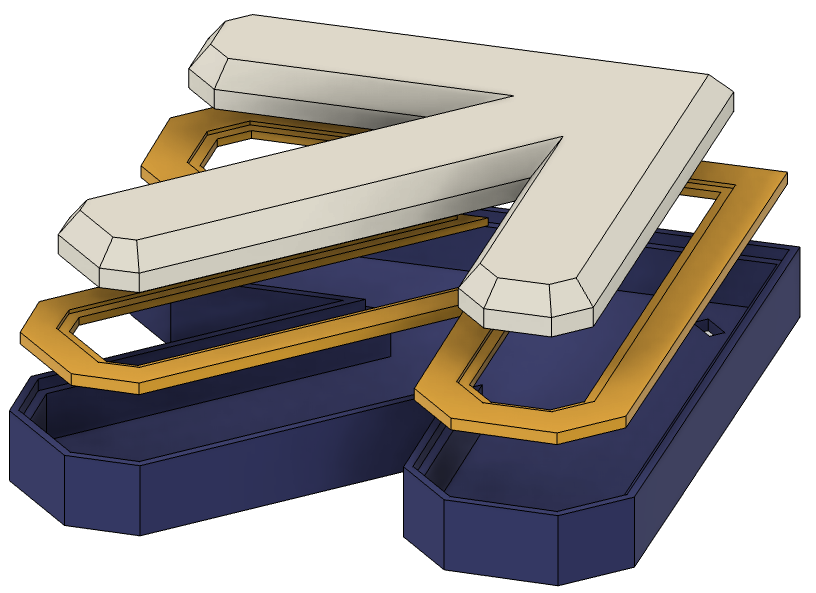
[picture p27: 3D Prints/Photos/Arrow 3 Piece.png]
Arrow 3 Piece

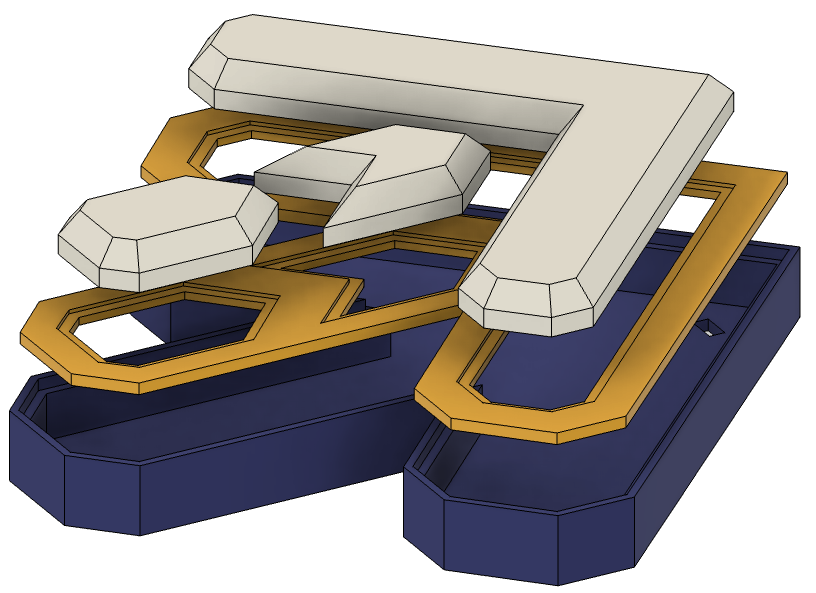
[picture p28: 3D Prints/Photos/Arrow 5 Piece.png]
Arrow 5 Piece

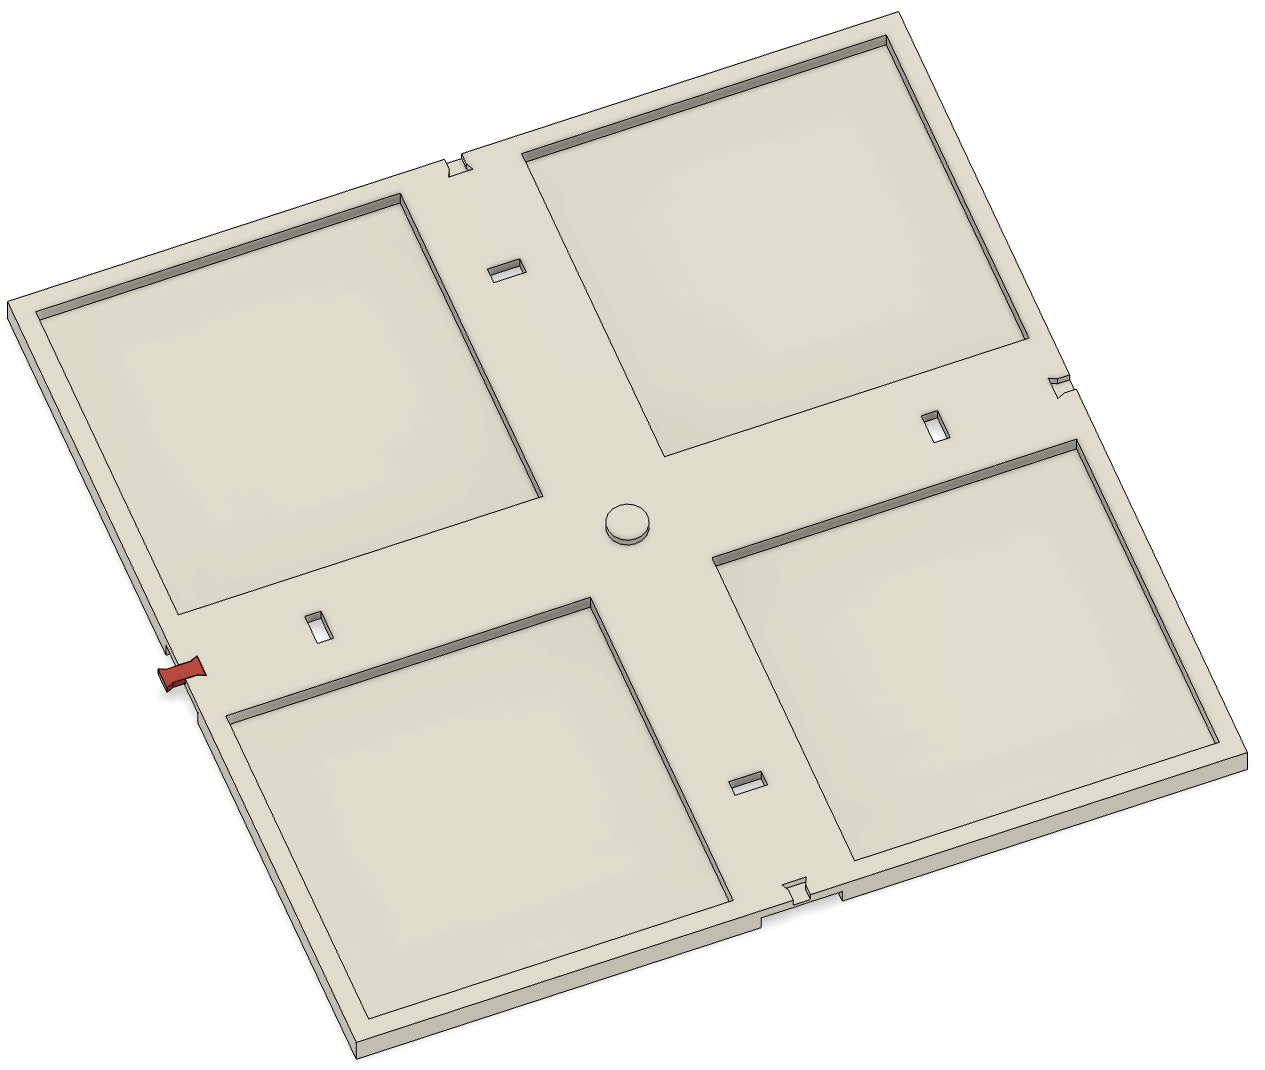
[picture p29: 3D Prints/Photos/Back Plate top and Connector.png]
Back Plate

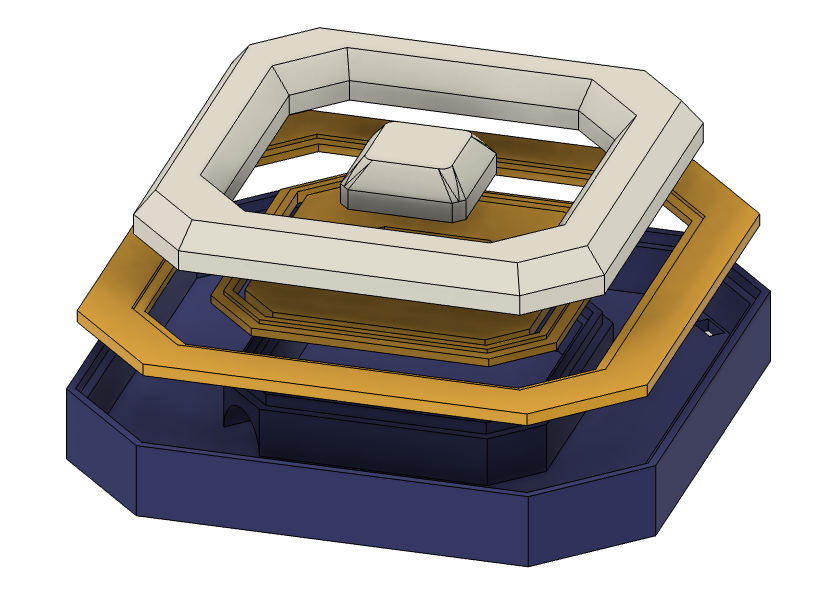
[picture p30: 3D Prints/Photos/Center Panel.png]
Center Panel

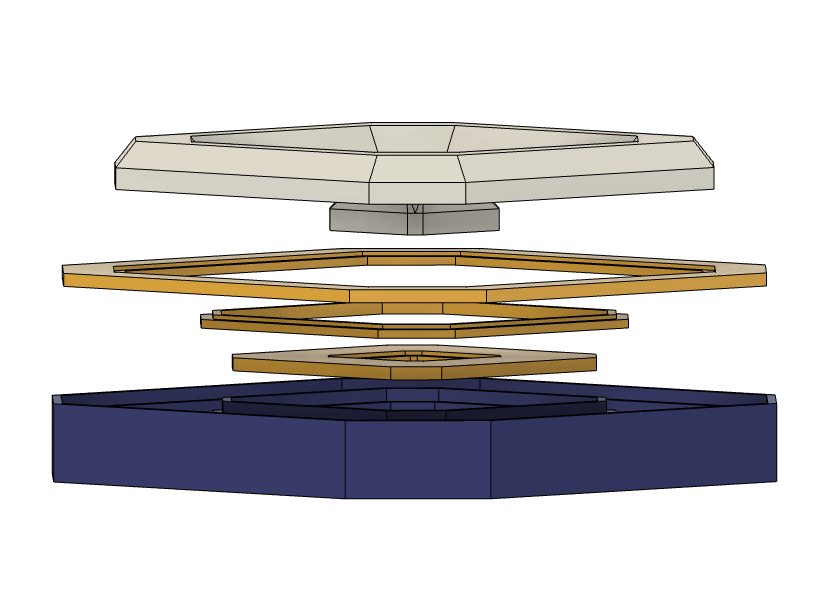
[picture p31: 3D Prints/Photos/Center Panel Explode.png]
Center Panel Explode


### Included Items
Breakdown of items included in this folder:
- [STL Model files for all pieces](./Models/STL/)
- [3MF Build Plate files specifically for the Bambu Labs X1-Carbon](./Models/3MF%20for%20Bambu%20Labs%20X1-Carbon)
- [A copy of the Fusion360 file used for modeling](./Models/SMX%20Items%20v2.f3d)

## Material
For this project I opted to print all of my models using OVERTURE PETG (Black, White, and Transparent).
I imagine you could very well print this in PLA or your material of choice, but keep in mind that PLA is stiffer and
more brittle. I feel like PETG is a good material for this as it's a little more forgiving to stress, bending, etc. 

I chose to use a Transparent filament for the top pieces so I get a good amount of light shining through, but I imagine
that you could just as easily use White, or some other light coloured material depending on how much light you want
to shine through. 

## What to Print
This guide assumes you want to print the full set of 4 cardinal arrows and 1 center arrow. 

The only bit of customization here would be the style of cardinal arrow you want to print. I have included
both a version with a single top piece, or a version with top piece split into three pieces. I believe the version split
into three pieces is the more "proper" design, but the single piece is most likely easier to print and simulates the
"cel" note skin for SMX. 

All that being said, here's what you'll need:
- 5 x Back Plate
- 4 x Back Plate Connector
- 1 x Center Base
- 1 x Center Insert Inner
- 1 x Center Insert Middle
- 1 x Center Insert Outer
- 1 x Center Top Inner
- 1 x Center Top Outer
- 4 x Arrow Base

If you want to print the three piece arrows you will also need:
- 4 x Arrow Insert for 3 Piece
- 4 x Arrow Top Head for 3 Piece
- 4 x Arrow Top Body for 3 Piece
- 4 x Arrow Top Tail for 3 Piece

If you want to print the one piece arrows instead, you will need:
- 4 x Arrow Insert for 1 Piece
- 4 x Arrow Top for 1 Piece

## Print Settings, Tips and Tricks

### Back Plate
The Back Plates can be a little tricky to print as they are not only very large, but need some considerable supports to
support the gap the wire channels on the bottom leave. I would suggest dailing in some good support settings and hope
for the best. At one point I tried using PLA as support material for my PETG Back Plates, but that didn't quite work
all that well. Your mileage may vary. 

General Print Settings:
- Layer Height: 0.2mm
- Walls: 4
- Surface Pattern: Monotonic Linear
- Top Layers: 5
- Bottom Pattern: Monotonic
- Bottom Layers: 3
- Infill: 25%
- Infill Pattern: Gyroid
- Support Type: Normal
- Support Interface Distance: 0.2mm
- Support Top Interface Layers: 3
- Brim Type: Outer Brim Only
- Brim Width: 10mm
- Brim-Object Gap: 0.08mm

### Back Plate Connector
Honestly, I found that this really wasn't enough to hold the plates together and I had to use a bunch of super glue, but
either way if you want a tight fit for this connector, you can try printing increasing the scale by small amounts until
you get the fit you are looking for. I suggest not scaling the height, so that it still ends up being flush.

Overall the print settings don't matter too much, but I suggest the following:
- Layer Height: 0.2mm or smaller
- Infill: 100%
- Brim Type: Outer Brim Only
- Brim Width: 3mm
- Brim-Object Gap: 0.2mm

### Insert Pieces
For the insert pieces, I opted to print them upside down and used supports for the overhangs. In this instance I found
using a different material for the interface layer (PLA for PETG) to work quite well.  The only reason I did this
was because I have a textured build plate and really like the texture on the bottom layers and wanted to have that
texture on the top side of my inserts. If you don't care about that, then just print them right side up and save
yourself the trouble. 

General Print Settings:
- Layer Height: 0.2mm
- Walls: 3
- Surface Pattern: Monotonic Linear
- Top Layers: 5
- Bottom Pattern: Monotonic
- Bottom Layers: 2
- Infill: 15%
- Infill Pattern: Gyroid
- Support Type: Normal
- Support Interface Material: PLA
- Support Interface Distance: 0 (This should probably be 0.2mm if you are using the same material)
- Support Top Interface Layers: 3
- Brim Type: Outer Brim Only
- Brim Width: 7mm
- Brim-Object Gap: 0.2mm

### Base Pieces
The Base pieces have an indent on the bottom for orientating them properly with the back plates. Again just try to find
some good overhang settings. In this instance I found using a different material for the interface layer (PLA for PETG)
to work quite well. 

General Print Settings:
- Layer Height: 0.2mm
- Walls: 3
- Surface Pattern: Monotonic Linear
- Top Layers: 5
- Bottom Pattern: Monotonic
- Bottom Layers: 2
- Infill: 10%
- Infill Pattern: Gyroid
- Support Type: Normal
- Support Interface Material: PLA
- Support Interface Distance: 0 (This should probably be 0.2mm if you are using the same material)
- Support Top Interface Layers: 3

### Top Pieces
For these pieces I would print them upside down (so the cavity is pointing up) and use a decently large brim. I 
personally had a lot of issues with bed adhesion as the surface area on the bed is fairly small. 

General Print Settings:
- Layer Height: 0.16mm
- Walls: 4
- Surface Pattern: Monotonic Linear
- Top Layers: 1
- Bottom Pattern: Hilbert Curve (For extra diffusion)
- Bottom Layers: 1
- Infill: 100%
- Infill Pattern: Aligned Rectilinear
- Support Type: None
- Brim Type: Outer Brim Only
- Brim Width: 15mm
- Brim-Object Gap: 0.2mm or 0.1mm if 0.2mm is giving you trouble still

# ⚠️ Warning ⚠️
At this point, I would suggest not gluing anything together. We will cover that in the `wiring` section.
